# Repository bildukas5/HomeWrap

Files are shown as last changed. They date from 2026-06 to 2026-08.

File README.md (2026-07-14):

# @HomeWrap 
# Canyon Endurace CF8 — Protective Film Cutouts

CAD cutout designs for applying protective film (TPU/vinyl) to the **Canyon Endurace CF8 frame, size M**.
Designed as a free, open-source alternative to commercial protective film kits.

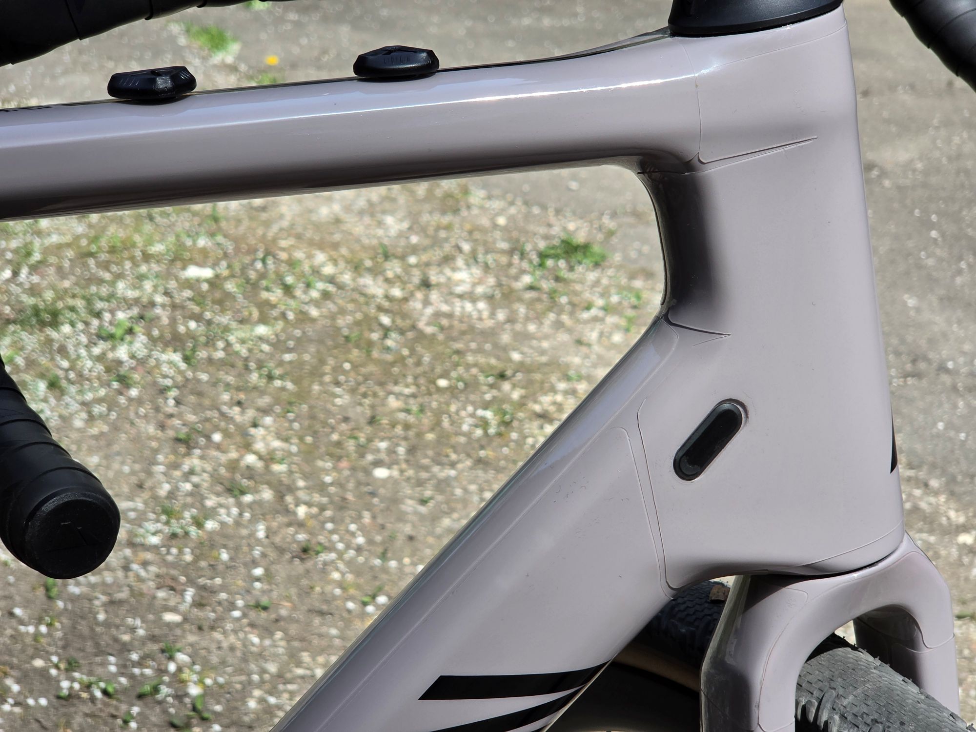
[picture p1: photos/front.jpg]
Frame coverage placeholder

<!-- Replace with an actual render or photo of the film applied to the frame -->

---

## Overview

- **Bike:** [Canyon Endurace CF8](https://www.canyon.com/en-lt/endurace-cf-8-di2/4363.html?dwvar_4363_pv_rahmenfarbe=R076_P10)
- **Frame size:** M
- **Coverage:** 90%+ of the frame
- **Money(?) shots:** [pics](https://github.com/bildukas5/HomeWrap/tree/main/photos)
- **CAD software:** [FreeCAD](https://www.freecad.org/) (free and open source)
- **License:** [CC BY-NC-SA 4.0](https://creativecommons.org/licenses/by-nc-sa/4.0/) — free for personal use, derivatives must stay open

---

## Files

| File | Description |
|---|---|
| `CAD/` | Native FreeCAD `.FCStd` files |
| `photos/` | Results |
| `DIY/` | Short tutorial |

---

## Getting Started

1. Download the files from the [CAD](https://github.com/bildukas5/HomeWrap/tree/main/CAD) page
2. Open `.FCStd` files in [FreeCAD](https://www.freecad.org/) to view or edit
3. Use the exported DXF/SVG files with your vinyl cutter or send to a print shop
4. If you don't have access to proper film cutter, you can resort to printing designs on paper and tracing them with snap-off blade (just as I did!)
5. I recommend to watch protectice film application tutorials on YouTube before you start 
6. I suggest starting with Head Tube and move on to Top/Down Tubes.

---

## Areas for improvement

1. I was working with 150 mm wide tape. Down Toube would benefit from 180 mm wide tape, Head Tube could use 160 mm.
2. Small, irregulary shaped patches went directly from masking tape to cutouts. No CAD files were made. Sorry!
3. Some corners were not properly rounded in CAD files. Make sure you don't leave any sharp corners as those will be first to peal off.
4. Some lines were not properly trimmed. Sorry!

---

## FAQ

**Is this as good as BrandWrap $200 kit?**
- No. This is an amateur first attempt at CAD design and bike protection. If you want professional results, buy a professional product.

**Is it better than BrandWrap $70 kit?**
- Possibly. It offers 90%+ frame coverage and is tailored specifically to this frame rather than being a generic cut.

**Can it be adapted to a different frame size?**
Probably, with some effort:
- **Fork and Chain Stay(?)** — should work without modification on all full-size wheel CF8 frames
- **Down Tube** — straightforward to make longer or shorter
- **Seat Tube and other parts** — may require more significant adjustments

---

## ⚠️ Disclaimer

- **No fit guarantee.** These designs were created for a specific Canyon Endurace CF8 frame size M. Frame tolerances, production batches, and measurement variations mean the cutouts may not fit your bike perfectly. **Always do a test run with paper or cheap material before cutting expensive TPU or vinyl film.**
- **Use at your own risk.** The author is not responsible for any damage to your bike, frame, components, or paint caused by the application, removal, or use of protective film based on these designs.
- **Film application can cause damage.** Improper application or removal of protective film can damage paint, carbon fiber, or decals. If in doubt, consult a professional.
- **No warranty.** These files are provided "as is", without warranty of any kind, express or implied. The author makes no guarantees about accuracy, fitness for purpose, or suitability for any particular use.
- **Not a professional product.** This is an amateur project. For critical protection or professional results, consider buying a professionally made kit.

---

## Contributing

Found an issue or improved the fit? Contributions are welcome!
Please open an [Issue](../../issues) or submit a Pull Request.
All contributions must be shared under the same [CC BY-NC-SA 4.0](https://creativecommons.org/licenses/by-nc-sa/4.0/) license.

---

## License

This project is licensed under **Creative Commons Attribution-NonCommercial-ShareAlike 4.0 International**.
You are free to use, share, and adapt these files for **personal, non-commercial use**, as long as you credit the original and share any modifications under the same license.

[View full license →](https://creativecommons.org/licenses/by-nc-sa/4.0/)

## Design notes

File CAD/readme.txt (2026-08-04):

For frame part namig visit: https://bestwheelset.com/all-parts-of-a-bike-a-complete-guide-for-beginners/

Files:

BB.FCStd - Underside of Bottom Bracket
ChainStay-CA.FCStd - Caliper side (left) Chain Stay
ChainStay-DR.FCStd - Drive side (right) Chain Stay
DownTube.FCStd - Down Tube
Fork-CA.FCStd - Caliper side (left) Fork
Fork-DR.FCStd - Drive side (right) Fork
HeadTube.FCStd - Head Tube
SeatBack.FCStd - Back of Seat Stay (under the seat)
SeatStay.FCStd - Seat Stay
TopTube.FCStd - Top Tube
SeatTube.FCStd - Seat Tube

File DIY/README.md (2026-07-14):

# How the Designs Were Made

This document explains the process used to create the protective film cutout designs.
It's a low-tech but effective approach that anyone can replicate without special equipment.

---

## Overview

The core idea is simple: use masking tape applied directly to the frame to capture the exact shape of each area, then transfer those shapes into CAD.

---

## Step 1 — Apply Masking Tape to the Frame

Apply masking tape directly onto the bicycle frame, covering the area you want to protect.
Layer tape on top of tape to build up a shape that holds together when removed.

**Tape choice matters.** A professional-grade masking tape makes this significantly easier:
- It has enough **stretch** to conform to curved and compound surfaces without wrinkling
- It leaves **no adhesive residue** on the frame
- It can be **repositioned and reapplied** multiple times while you refine the shape

In this project, **TESA Pro** masking tape was used and worked very well. Any high-quality automotive or professional masking tape with similar properties should work.

> ⚠️ Avoid cheap masking tape — it tears easily, leaves residue, and doesn't stretch around curves.

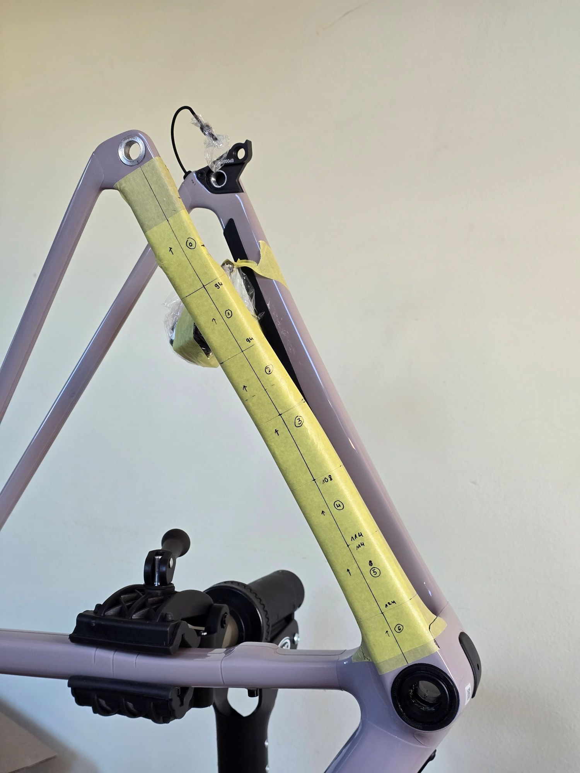
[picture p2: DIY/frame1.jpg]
frame1

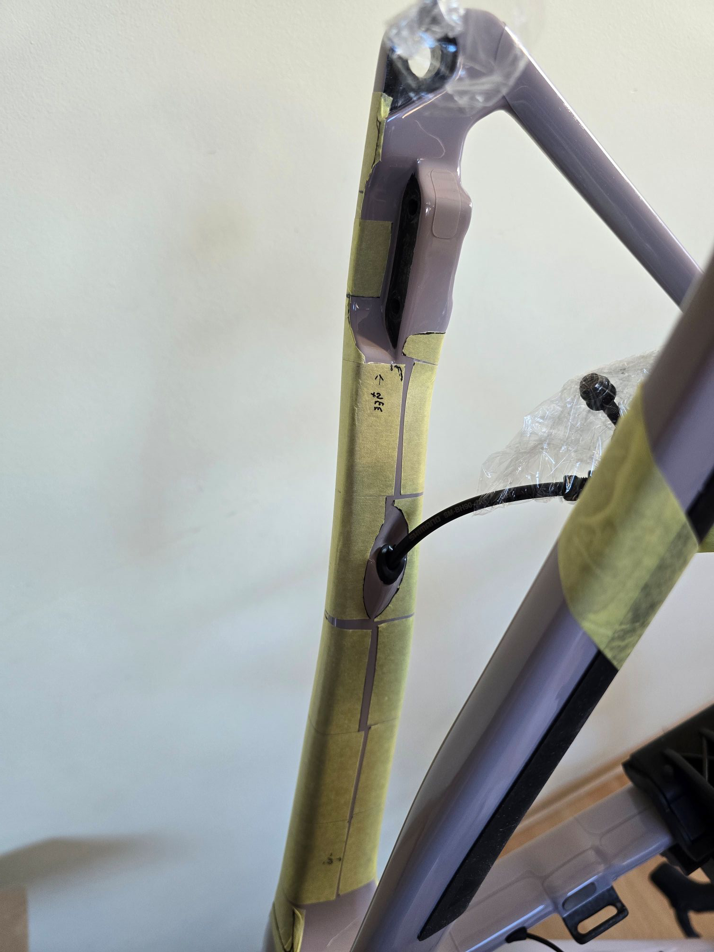
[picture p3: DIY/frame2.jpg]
frame2

---

## Step 2 — Trim the Shape

While the tape is still on the frame, carefully trim it to the exact edge of the area you want to cover. Precision scissors work well for this.

Take your time — the accuracy of this step directly affects how well the final film fits.

---

## Step 3 — Remove and Flatten

Carefully peel the tape shape off the frame and lay it flat on a cutting board or other flat surface.
Smooth it out as much as possible — the tape's flexibility means it will lie reasonably flat even for curved pieces.

---

## Step 4 — Measure

With the tape shape flat on the cutting board, take manual measurements of all key dimensions:
- Overall length and width
- Curves and radii where possible
- Any cutouts or notches
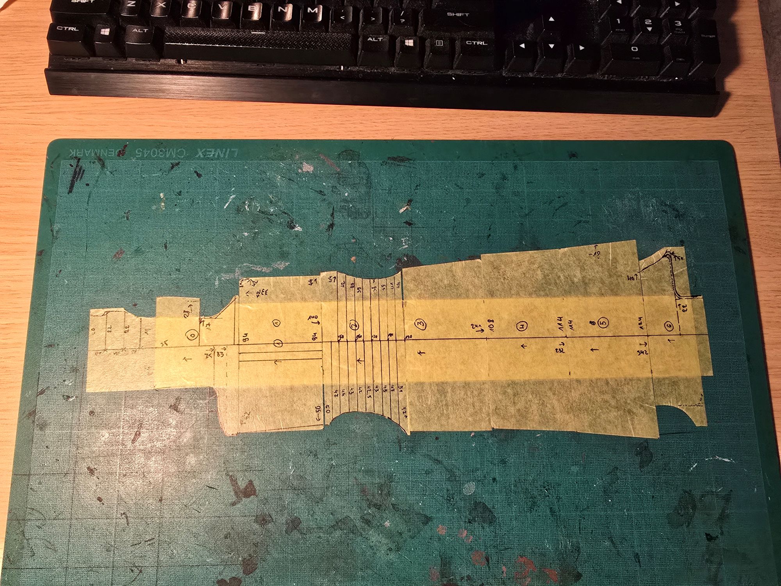
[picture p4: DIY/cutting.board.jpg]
cb

---

## Step 5 — Recreate in FreeCAD

Using the measurements taken in the previous step, recreate each shape as a 2D sketch in [FreeCAD](https://www.freecad.org/).

- Use the **Sketcher workbench** to draw and constrain the shapes
- Add dimensions as constraints to match your measurements
- Export finished sketches as **DXF or SVG** for cutting

FreeCAD is free and open source, which fits the spirit of this project.

---

## Alternative: Direct Transfer for Small or Complex Areas

Some areas of the frame are small, heavily curved, or have such an irregular shape that accurately measuring and recreating them in CAD is impractical. For these, the masking tape shape was used as a direct cutting template — skipping the CAD step entirely.

The process is straightforward:
1. Remove the tape shape from the frame as usual and flatten it on the cutting board
2. Place it directly onto the protective film
3. Trace around it with a marker or cut directly along its edge
4. Apply the resulting piece to the frame

This is less precise than a CAD-derived cut but works well for small patches where slight imperfections are less noticeable. It's also much faster for one-off pieces you don't need to reproduce exactly.
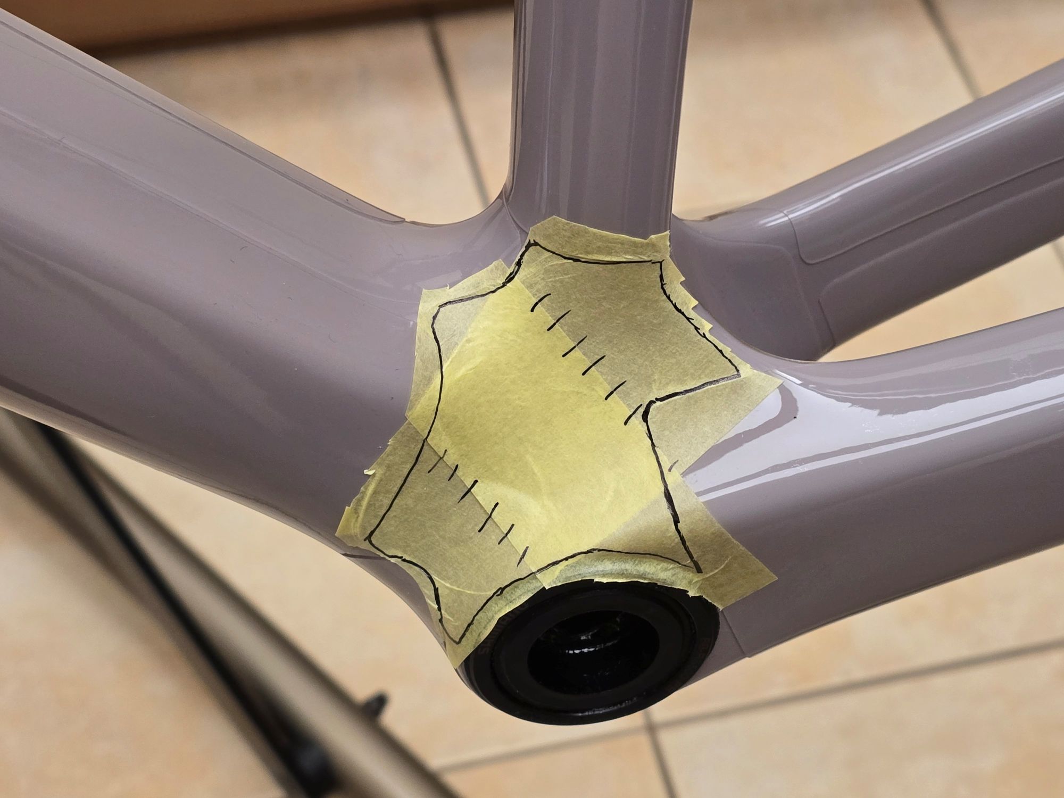
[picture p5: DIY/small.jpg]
small

---

## Tips & Lessons Learned

- **Label each tape piece** before removing it from the frame so you don't mix them up
- **Photograph the tape on the frame** before removing — useful reference if a measurement is unclear later
- **Test with paper before film** — print or cut a paper version first to verify fit before using real PPF or vinyl

---

## Tools Used

| Tool | Purpose |
|---|---|
| TESA Pro masking tape | Capturing frame shapes |
| Precision scissors | Trimming tape on the frame |
| Cutting board | Flat surface for measuring |
| Ruler + calipers | Taking measurements |
| [FreeCAD](https://www.freecad.org/) | Creating CAD designs from measurements |

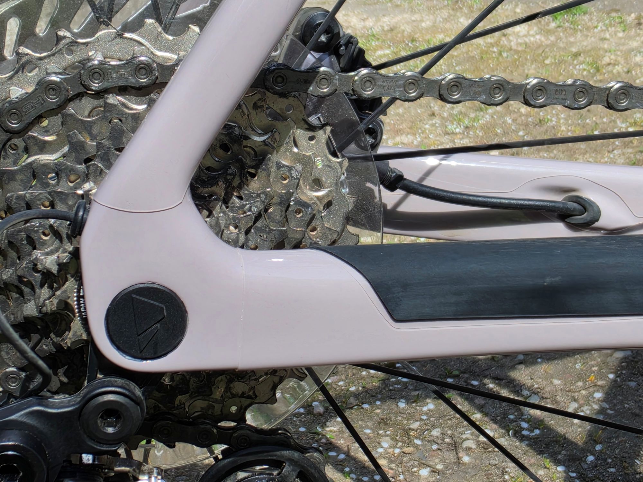
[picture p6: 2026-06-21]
photos/chain-post.jpg

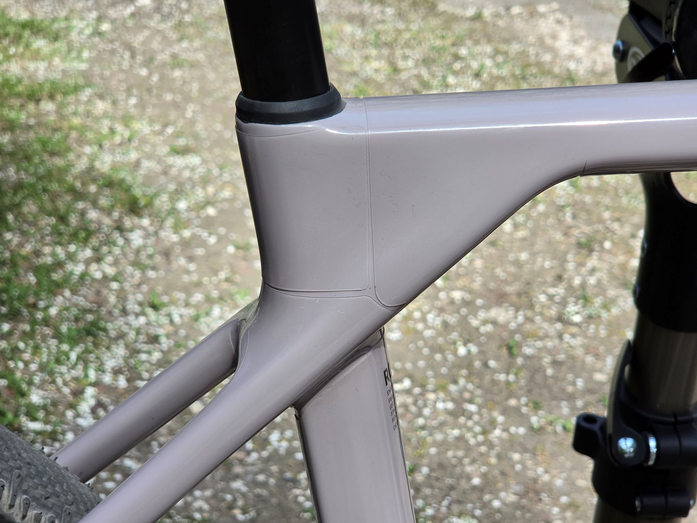
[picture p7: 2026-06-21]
photos/seat-post.jpg

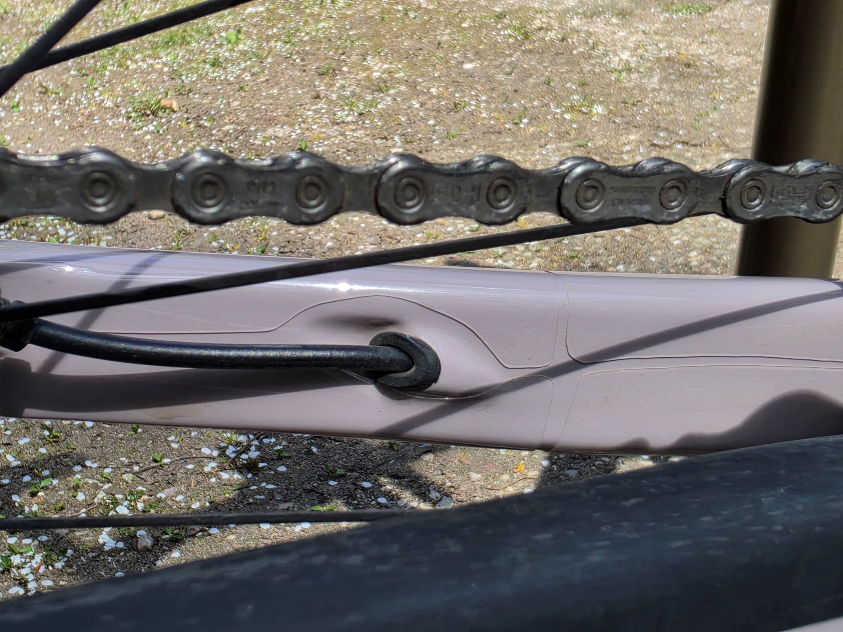
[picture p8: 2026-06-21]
photos/chain-post2.jpg

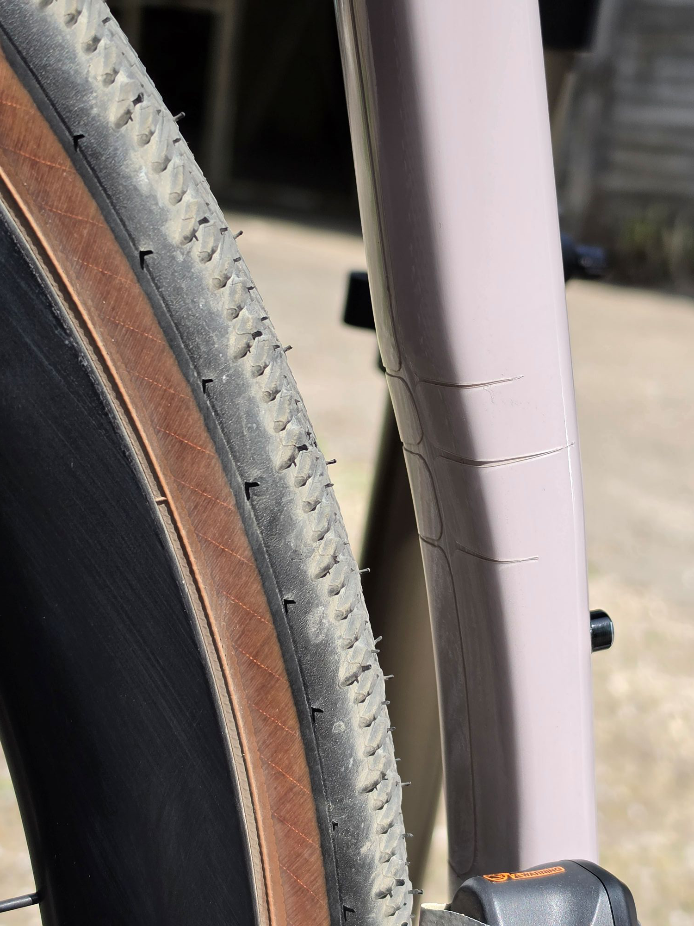
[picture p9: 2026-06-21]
photos/seat-post3.jpg

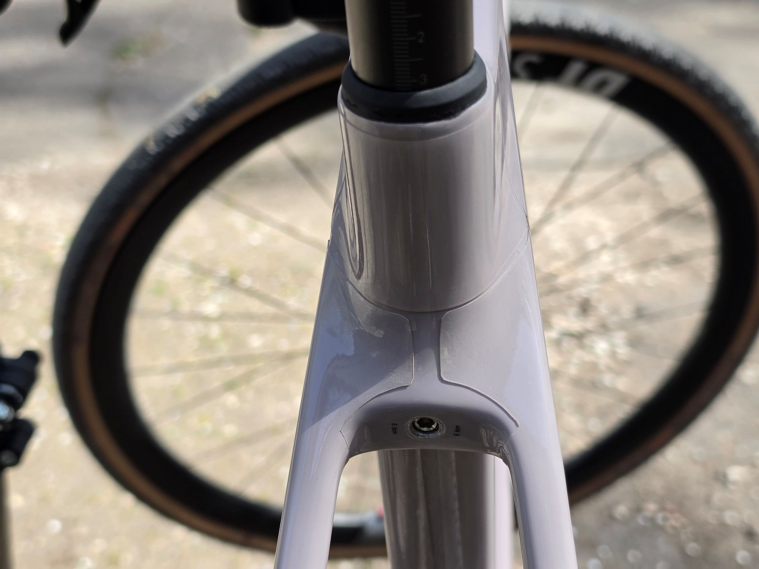
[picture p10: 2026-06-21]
photos/seat-post2.jpg

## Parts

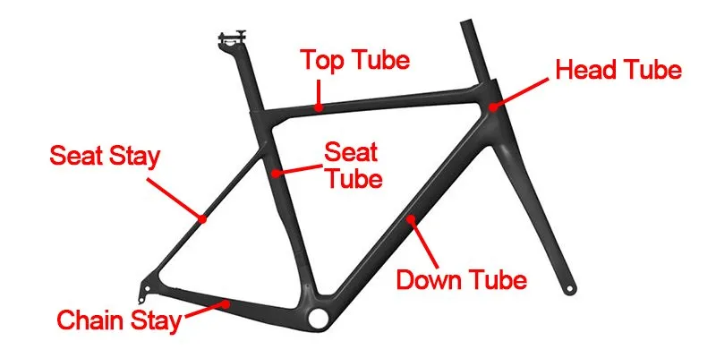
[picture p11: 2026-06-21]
CAD/Parts-of-The-Frame.webp

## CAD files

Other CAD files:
CAD/SeatTube.FCStd
CAD/SeatBack.FCStd
CAD/Fork-DR.FCStd
CAD/HeadTube.FCStd
CAD/DownTube.FCStd
CAD/SeatStay.FCStd
CAD/ChainStay-CA.FCStd
CAD/TopTube.FCStd
CAD/BB.FCStd
CAD/Fork-CA.FCStd
CAD/ChainStay-DR.FCStd

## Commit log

2026-06-21 Update README with areas for improvement
    Added notes on CAD file improvements and corner rounding.
2026-06-22 Update disclaimer regarding material types
2026-07-14 Fix image path for frame1 in README
    Updated image path for frame1 in README.
